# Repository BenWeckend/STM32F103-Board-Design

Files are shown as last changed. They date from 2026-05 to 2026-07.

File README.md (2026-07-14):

# STM32F103 Board Design

## Überblick

Hardware-Referenzdesign und Firmware für ein Übungs-Entwicklungsboard auf Basis des **STM32F103C8T6** mit CAN, USB, I²C (BME280) und weiterer Peripherie.

Das Repository enthält:

* KiCad-Schaltplan und PCB-Design
* Gerber- und Fertigungsdaten
* Stückliste (BOM)
* STM32CubeIDE Firmware-Projekt
* Tauri Desktop-Anwendung zur Kommunikation mit dem Board

---

## Hardware

### Schaltplan

<p align="center">
  <a href="https://github.com/user-attachments/assets/53ac5396-df05-4695-8c12-381431206e39">
    STM32F103 Schaltplan
  </a>
</p>

<p align="center">
  Vollständiger Schaltplan des STM32F103-Boards mit CAN, USB, Spannungsversorgung und BME280-Sensor.
</p>

### 3D-Ansicht der Platine

<p align="center">
  <a href="https://github.com/user-attachments/assets/49a3485b-9462-442f-9252-74b04783f217">
    3D PCB Rendering
  </a>
</p>

<p align="center">
  3D-Vorschau der fertig bestückten Leiterplatte aus KiCad.
</p>

---

## Projektstruktur

| Ordner | Beschreibung |
| --- | --- |
| `kicad/` | Schaltplan, PCB-Layout und Fertigungsdaten |
| `firmware/` | STM32CubeIDE-Projekt |
| `tauri-app/` | Desktop-Anwendung (Rust + Frontend) |

---

## Hauptfunktionen

### Mikrocontroller

* `STM32F103C8T6` (LQFP48)

### Kommunikation

* CAN-Bus über `TJA1051`
* USB Micro-B Device Interface

### Sensorik

* `BME280` (I²C)

  * Temperatur
  * Luftdruck
  * Luftfeuchtigkeit

### Spannungsversorgung

* `AMS1117-3.3`
* Onboard 3.3V-Regler

### Debugging & Programmierung

* SWD Header
* ST-Link kompatibel
* STM32CubeProgrammer kompatibel

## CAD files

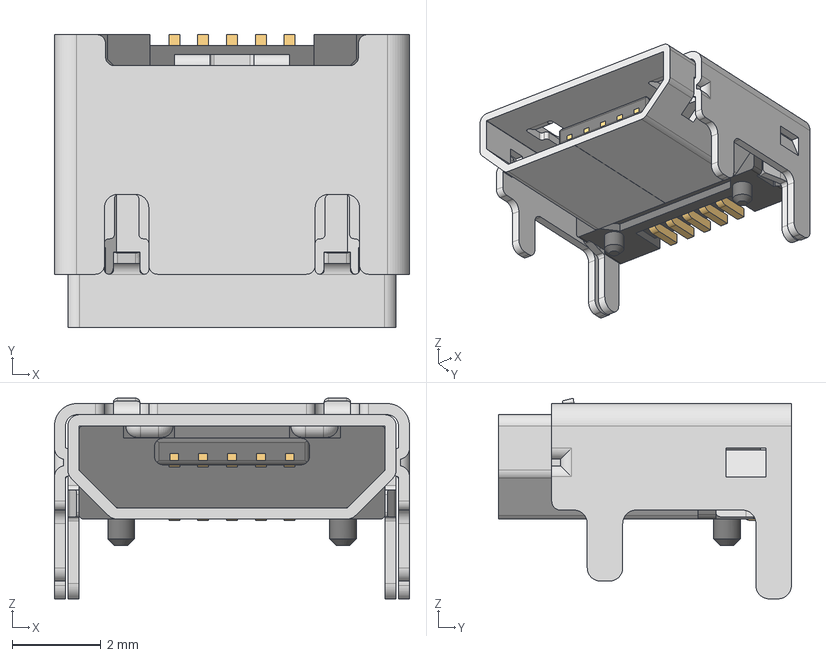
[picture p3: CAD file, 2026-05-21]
kicad/629105150521 (rev1).stp
8.00 x 6.60 x 4.52 mm
629105150521_Housing
629105150521_Pin1 x 4
629105150521_Pin2
629105150521_Shielding2
629105150521_Shielding

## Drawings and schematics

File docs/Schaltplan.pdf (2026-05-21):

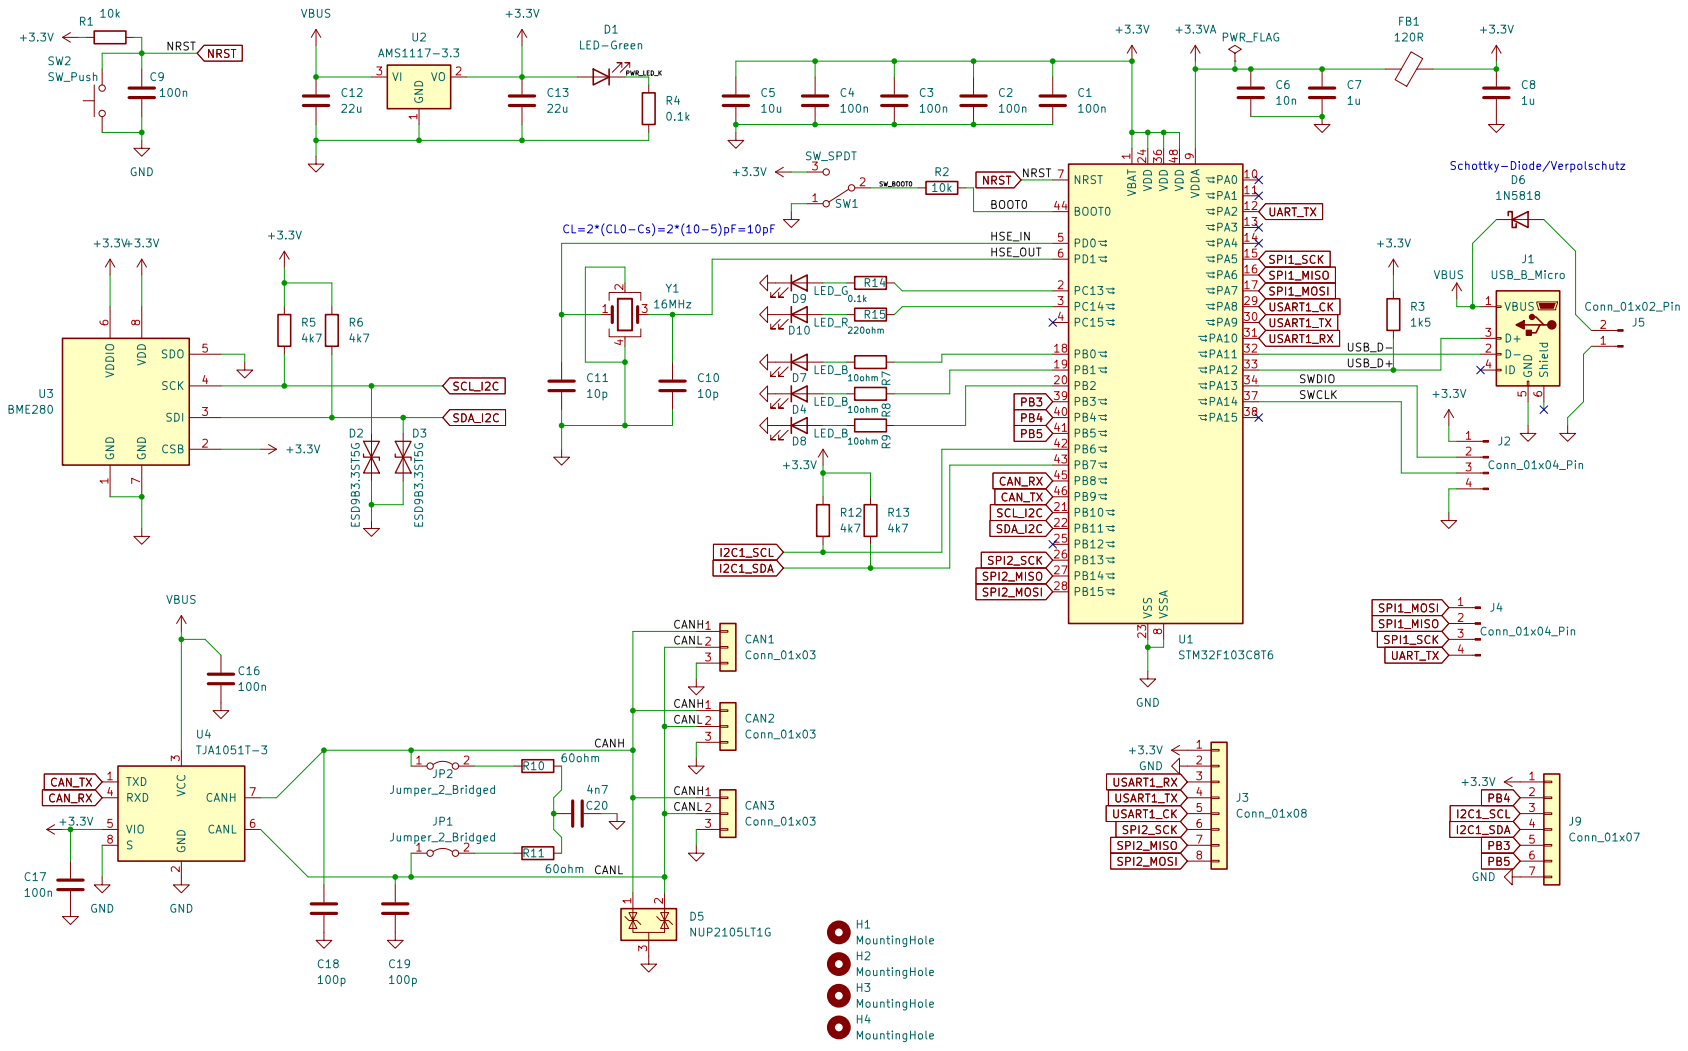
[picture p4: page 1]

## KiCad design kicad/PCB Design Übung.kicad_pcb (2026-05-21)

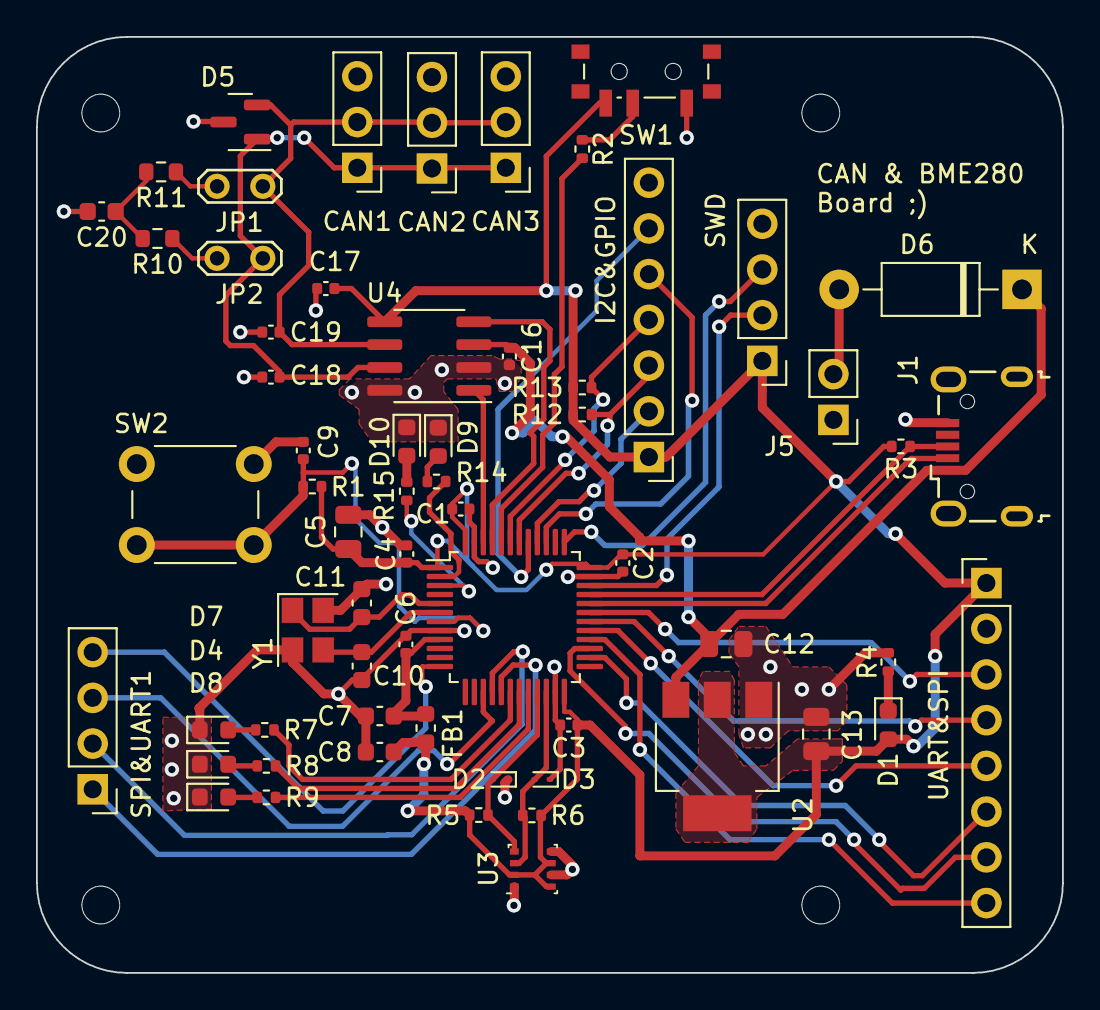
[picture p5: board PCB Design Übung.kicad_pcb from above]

Board: 2 copper layers, 57.0 x 52.0 mm, 66 parts (0 on the bottom side), 49 nets.

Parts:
C1, C2, C3, C4, C9, C16, C17: 100n; C_0402_1005Metric
C5: 10u; C_0805_2012Metric
C6: 10n; C_0402_1005Metric
C7, C8: 1u; C_0603_1608Metric
C10, C11: 10p; C_0603_1608Metric
C12, C13: 22u; C_0805_2012Metric
C18, C19: 100p; C_0402_1005Metric
C20: 4n7; C_0603_1608Metric
CAN1, CAN2, CAN3: Conn_01x03; PinHeader_1x03_P2.54mm_Vertical
D1: LED-Green; LED_0603_1608Metric
D2, D3: ESD9B3.3ST5G; D_SOD-923
D4, D7, D8: LED_B; LED_0603_1608Metric
D5: NUP2105LT1G; SOT-23
D6: 1N5818; D_DO-41_SOD81_P10.16mm_Horizontal
D9: LED_G; LED_0603_1608Metric
D10: LED_R; LED_0603_1608Metric
FB1: 120R; L_0603_1608Metric
H1, H2, H3, H4: MountingHole; MountingHole_2.1mm
I2C&GPIO: Conn_01x07; PinHeader_1x07_P2.54mm_Vertical
J1: USB_B_Micro; USB_Micro-B_Wuerth_629105150521
J5: Conn_01x02_Pin; PinHeader_1x02_P2.54mm_Vertical
JP1, JP2: Jumper_2_Bridged; TestPoint_2Pads_Pitch2.54mm_Drill0.8mm
R1, R2: 10k; R_0402_1005Metric
R3: 1k5; R_0402_1005Metric
R4, R14: 0.1k; R_0402_1005Metric
R5, R6, R12, R13: 4k7; R_0402_1005Metric
R7, R8, R9: 10ohm; R_0402_1005Metric
R10, R11: 60ohm; R_0603_1608Metric
R15: 220ohm; R_0402_1005Metric
SPI&UART1: Conn_01x04_Pin; PinHeader_1x04_P2.54mm_Vertical
SW1: SW_SPDT; SW_SPDT_PCM12
SW2: SW_Push; SW_PUSH_6mm
SWD: Conn_01x04_Pin; PinHeader_1x04_P2.54mm_Vertical
U1: STM32F103C8T6; LQFP-48_7x7mm_P0.5mm
U2: AMS1117-3.3; SOT-223-3_TabPin2
U3: BME280; Bosch_LGA-8_2.5x2.5mm_P0.65mm_ClockwisePinNumbering
U4: TJA1051T-3; SOIC-8_3.9x4.9mm_P1.27mm
UART&SPI: Conn_01x08; PinHeader_1x08_P2.54mm_Vertical
Y1: 16MHz; Crystal_SMD_3225-4Pin_3.2x2.5mm

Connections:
+3.3V: C1.1, C2.1, C3.1, C4.1, C5.1, C8.1, C13.1, C17.1, D1.2 (A), FB1.2, I2C&GPIO.1, R1.2, R3.1, R5.1, R6.1, R12.1, R13.1, SW1.3 (C), SWD.1, U1.1 (VBAT), U1.24 (VDD), U1.36 (VDD), U1.48 (VDD), U2.2 (VO), U3.2 (CSB), U3.6 (VDDIO), U3.8 (VDD), U4.5 (VIO), UART&SPI.1
+3.3VA: C6.1, C7.1, FB1.1, U1.9 (VDDA)
/BOOT0: R2.2, U1.44 (BOOT0)
/CANH: C18.1, CAN1.1, CAN2.1, CAN3.1, D5.1 (K), JP2.1 (A), U4.7 (CANH)
/CANL: C19.1, CAN1.2, CAN2.2, CAN3.2, D5.2 (K), JP1.1 (A), U4.6 (CANL)
/HSE_IN: C11.1, U1.5 (PD0), Y1.1
/HSE_OUT: C10.1, U1.6 (PD1), Y1.3
/PWR_LED_K: D1.1 (K), R4.1
/SWCLK: SWD.3, U1.37 (PA14)
/SWDIO: SWD.2, U1.34 (PA13)
/SW_BOOT0: R2.1, SW1.2 (B)
/USB_D+: J1.3 (D+), R3.2, U1.33 (PA12)
/USB_D-: J1.2 (D-), U1.32 (PA11)
CAN_RX: U1.45 (PB8), U4.4 (RXD)
CAN_TX: U1.46 (PB9), U4.1 (TXD)
GND: C1.2, C2.2, C3.2, C4.2, C5.2, C6.2, C7.2, C8.2, C9.2, C10.2, C11.2, C12.2, C13.2, C16.2, C17.2, C18.2, C19.2, C20.2, CAN1.3, CAN2.3, CAN3.3, D2.1 (A1), D3.1 (A1), D4.1 (K), D5.3 (A), D7.1 (K), D8.1 (K), D9.1 (K), D10.1 (K), I2C&GPIO.7, J1.5 (GND), J5.1, R4.2, SW1.1 (A), SW2.1, SWD.4, U1.8 (VSSA), U1.23 (VSS), U1.35 (VSS), U1.47 (VSS), U2.1 (GND), U3.1 (GND), U3.5 (SDO), U3.7 (GND), U4.2 (GND), U4.8 (S), UART&SPI.2, Y1.2, Y1.4
I2C1_SCL: I2C&GPIO.3, R12.2, U1.42 (PB6)
I2C1_SDA: I2C&GPIO.4, R13.2, U1.43 (PB7)
NRST: C9.1, R1.1, SW2.2, U1.7 (NRST)
unnamed: C20.1, R10.2, R11.2
unnamed: D4.2 (A), R8.2
unnamed: D6.2 (A), J5.2
unnamed: D7.2 (A), R7.2
unnamed: D8.2 (A), R9.2
unnamed: D9.2 (A), R14.2
unnamed: D10.2 (A), R15.2
unnamed: JP1.2 (B), R11.1
unnamed: JP2.2 (B), R10.1
unnamed: R7.1, U1.18 (PB0)
unnamed: R8.1, U1.19 (PB1)
unnamed: R9.1, U1.20 (PB2)
unnamed: R14.1, U1.2 (PC13)
unnamed: R15.1, U1.3 (PC14)
PB3: I2C&GPIO.5, U1.39 (PB3)
PB4: I2C&GPIO.2, U1.40 (PB4)
PB5: I2C&GPIO.6, U1.41 (PB5)
SCL_I2C: D2.2 (A2), R5.2, U1.21 (PB10), U3.4 (SCK)
SDA_I2C: D3.2 (A2), R6.2, U1.22 (PB11), U3.3 (SDI)
SPI1_MISO: SPI&UART1.2, U1.16 (PA6)
SPI1_MOSI: SPI&UART1.1, U1.17 (PA7)
SPI1_SCK: SPI&UART1.3, U1.15 (PA5)
SPI2_MISO: U1.27 (PB14), UART&SPI.7
SPI2_MOSI: U1.28 (PB15), UART&SPI.8
SPI2_SCK: U1.26 (PB13), UART&SPI.6
UART_TX: SPI&UART1.4, U1.12 (PA2)
USART1_CK: U1.29 (PA8), UART&SPI.5
USART1_RX: U1.31 (PA10), UART&SPI.3
USART1_TX: U1.30 (PA9), UART&SPI.4
VBUS: C12.1, C16.1, D6.1 (K), J1.1 (VBUS), U2.3 (VI), U4.3 (VCC)

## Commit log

2026-06-07 Update README with schematic and 3D construction images
    Added images and description for schematic and 3D construction.
2026-06-07 Revise README for STM32F103 Board Design details
    Updated README.md to provide a comprehensive overview of the STM32F103 Board Design, including hardware references, project structure, main features, and firmware development instructions.
2026-07-14 Clarify board purpose in README
    Updated the description to clarify the board's purpose.
